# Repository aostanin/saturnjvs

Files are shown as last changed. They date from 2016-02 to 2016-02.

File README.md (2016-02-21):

# SaturnJVS

A project to build a replacement JVS I/O board for a NAOMI arcade board which uses Sega Saturn controllers as input.

## Details

This relies on two boards which communicate by I2C. One board handles JVS communication with the NAOMI while the other handles controller input from Sega Saturn controllers. Originally, the plan was to support different types of controllers by swapping controller input boards.

Both boards rely on Atmel AVR ATmega328P microcontrollers and the firmware is written using the Arduino framework. The boards, however, are custom made and not arduino boards (though Arduino boards might be usable as well).

## Status

Using standard Sega Saturn controllers to play games on a NAOMI 2 board works well. There are some missing features including analog pad support and button remapping.

This project is on hold.

## Directory Layout

- `eagle`: Eagle schematics and board layout data.
- `naomi_io`: Firmware for the JVS communication board.
- `saturn_js`: Firmware for the Sega Saturn controller board.

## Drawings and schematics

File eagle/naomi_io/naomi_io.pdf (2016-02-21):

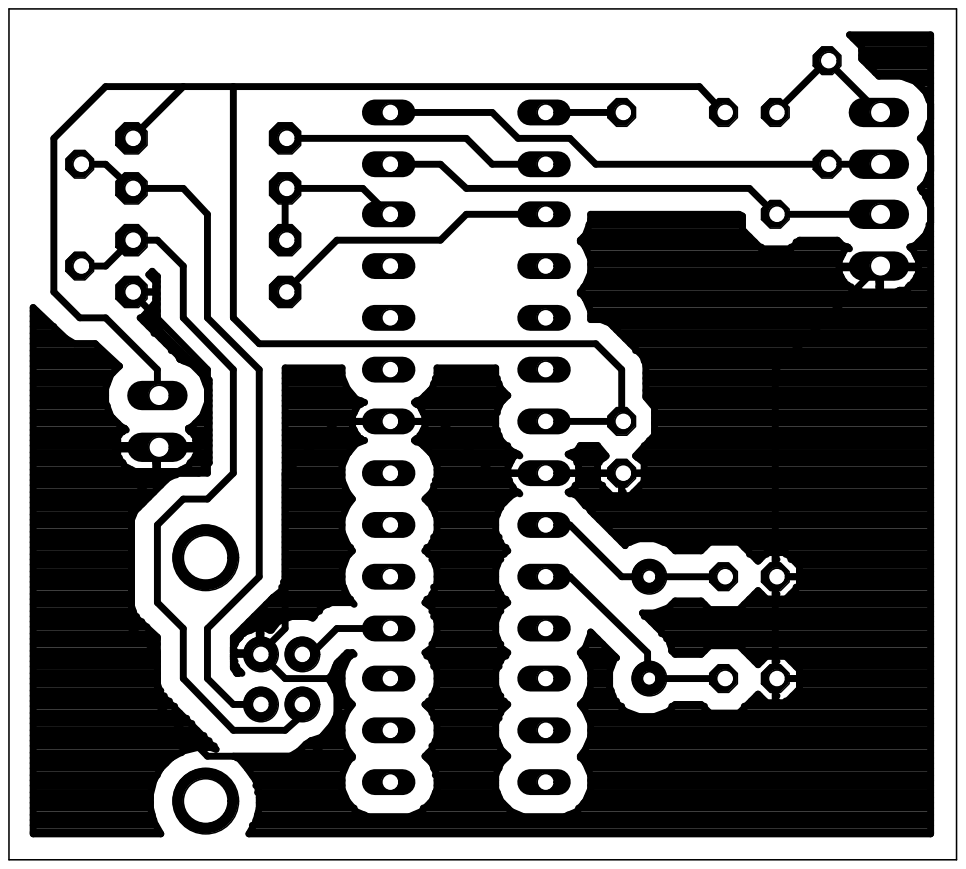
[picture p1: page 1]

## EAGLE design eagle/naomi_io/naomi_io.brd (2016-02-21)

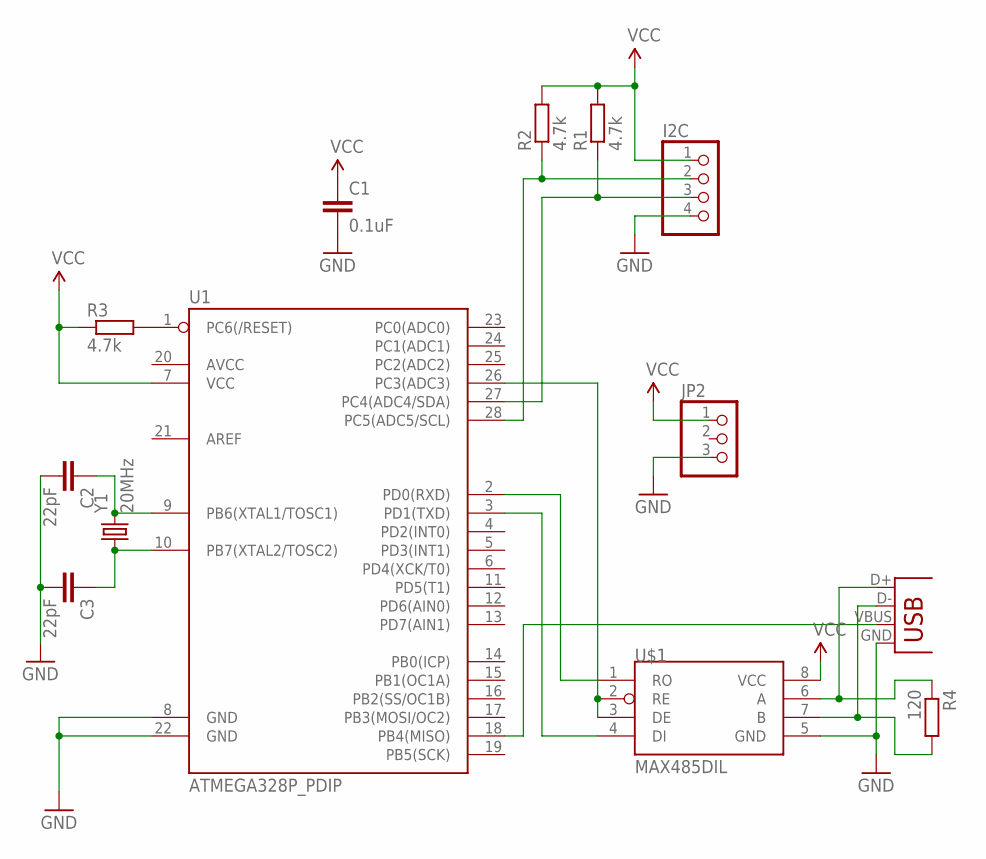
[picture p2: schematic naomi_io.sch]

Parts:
C1: 0.1uF; C025-030X050
C2, C3: 22pF; C025-030X050
I2C: PINHD-1X4/90; 1X04/90
JP1: USB-B; USB-B-PTH
JP2: PINHD-1X3; 1X03
R1, R2, R3: 4.7k; 0204/5
R4: 120; 0204/5
U1: ATMEGA328P_PDIP; DIL28-3
U$1: MAX485DIL; DIL08
Y1: 20MHz; HC49US

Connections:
GND: C1.2, C2.2, C3.2, I2C.4, JP1.GND, JP2.3, U1.8 (GND), U1.22 (GND), U$1.5 (GND)
unnamed: I2C.2, R2.1, U1.28 (PC5(ADC5/SCL))
unnamed: I2C.3, R1.1, U1.27 (PC4(ADC4/SDA))
unnamed: R3.2, U1.1 (PC6(/RESET))
unnamed: JP1.D-, R4.2, U$1.7 (B)
unnamed: U1.2 (PD0(RXD)), U$1.1 (RO)
unnamed: U1.3 (PD1(TXD)), U$1.4 (DI)
unnamed: JP1.VBUS, U1.18 (PB4(MISO))
unnamed: U1.26 (PC3(ADC3)), U$1.2 (RE), U$1.3 (DE)
unnamed: C2.1, U1.9 (PB6(XTAL1/TOSC1)), Y1.2
unnamed: C3.1, U1.10 (PB7(XTAL2/TOSC2)), Y1.1
unnamed: JP1.D+, R4.1, U$1.6 (A)
VCC: C1.1, I2C.1, JP2.1, R1.2, R2.2, R3.1, U1.7 (VCC), U$1.8 (VCC)

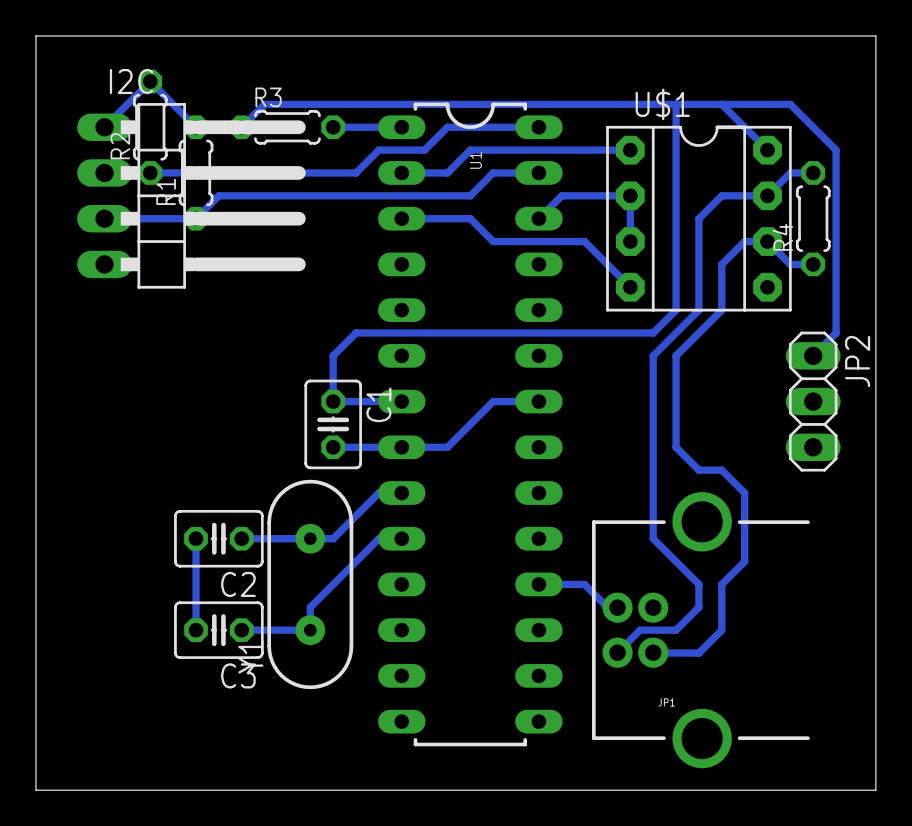
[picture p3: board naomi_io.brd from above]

Board: 2 copper layers, 46.7 x 41.9 mm, 13 parts (0 on the bottom side), 13 nets.

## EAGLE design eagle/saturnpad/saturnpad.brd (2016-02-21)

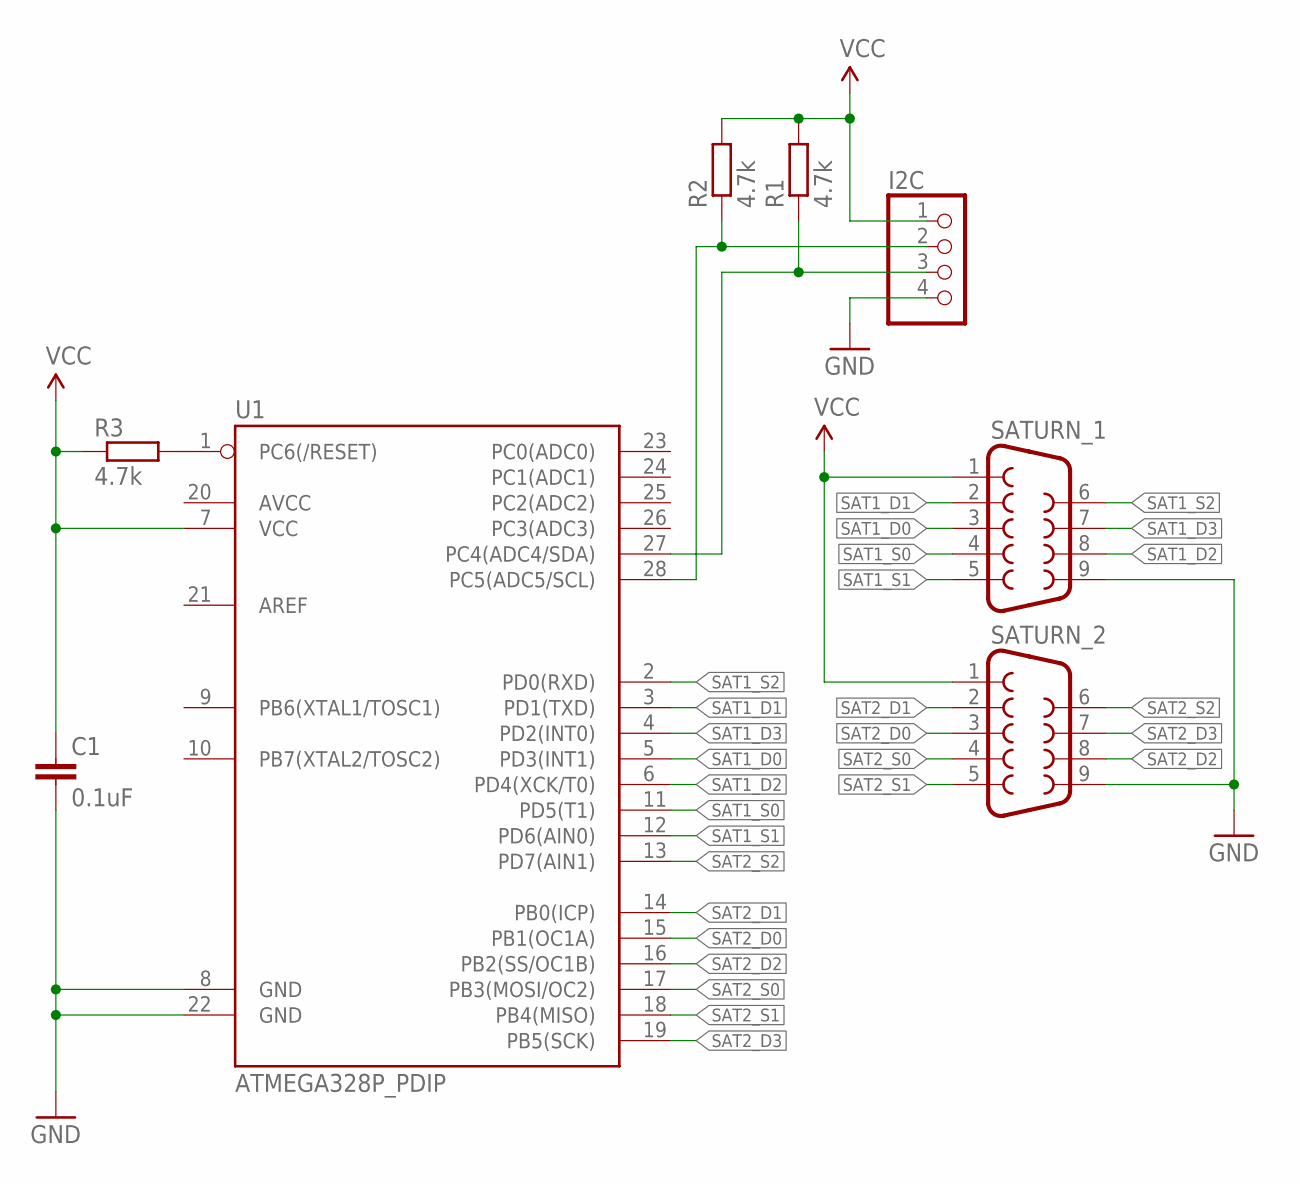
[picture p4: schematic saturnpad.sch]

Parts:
C1: 0.1uF; C025-030X050
I2C: PINHD-1X4/90; 1X04/90
R1, R2, R3: 4.7k; 0204/5
SATURN_1, SATURN_2: DB9MALE; DB9_MALE
U1: ATMEGA328P_PDIP; DIL28-3

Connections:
GND: C1.2, I2C.4, SATURN_1.9, SATURN_2.9, U1.8 (GND), U1.22 (GND)
unnamed: I2C.2, R2.1, U1.28 (PC5(ADC5/SCL))
unnamed: I2C.3, R1.1, U1.27 (PC4(ADC4/SDA))
unnamed: R3.2, U1.1 (PC6(/RESET))
SAT1_D0: SATURN_1.3, U1.5 (PD3(INT1))
SAT1_D1: SATURN_1.2, U1.3 (PD1(TXD))
SAT1_D2: SATURN_1.8, U1.6 (PD4(XCK/T0))
SAT1_D3: SATURN_1.7, U1.4 (PD2(INT0))
SAT1_S0: SATURN_1.4, U1.11 (PD5(T1))
SAT1_S1: SATURN_1.5, U1.12 (PD6(AIN0))
SAT1_S2: SATURN_1.6, U1.2 (PD0(RXD))
SAT2_D0: SATURN_2.3, U1.15 (PB1(OC1A))
SAT2_D1: SATURN_2.2, U1.14 (PB0(ICP))
SAT2_D2: SATURN_2.8, U1.16 (PB2(SS/OC1B))
SAT2_D3: SATURN_2.7, U1.19 (PB5(SCK))
SAT2_S0: SATURN_2.4, U1.17 (PB3(MOSI/OC2))
SAT2_S1: SATURN_2.5, U1.18 (PB4(MISO))
SAT2_S2: SATURN_2.6, U1.13 (PD7(AIN1))
VCC: C1.1, I2C.1, R1.2, R2.2, R3.1, SATURN_1.1, SATURN_2.1, U1.7 (VCC)

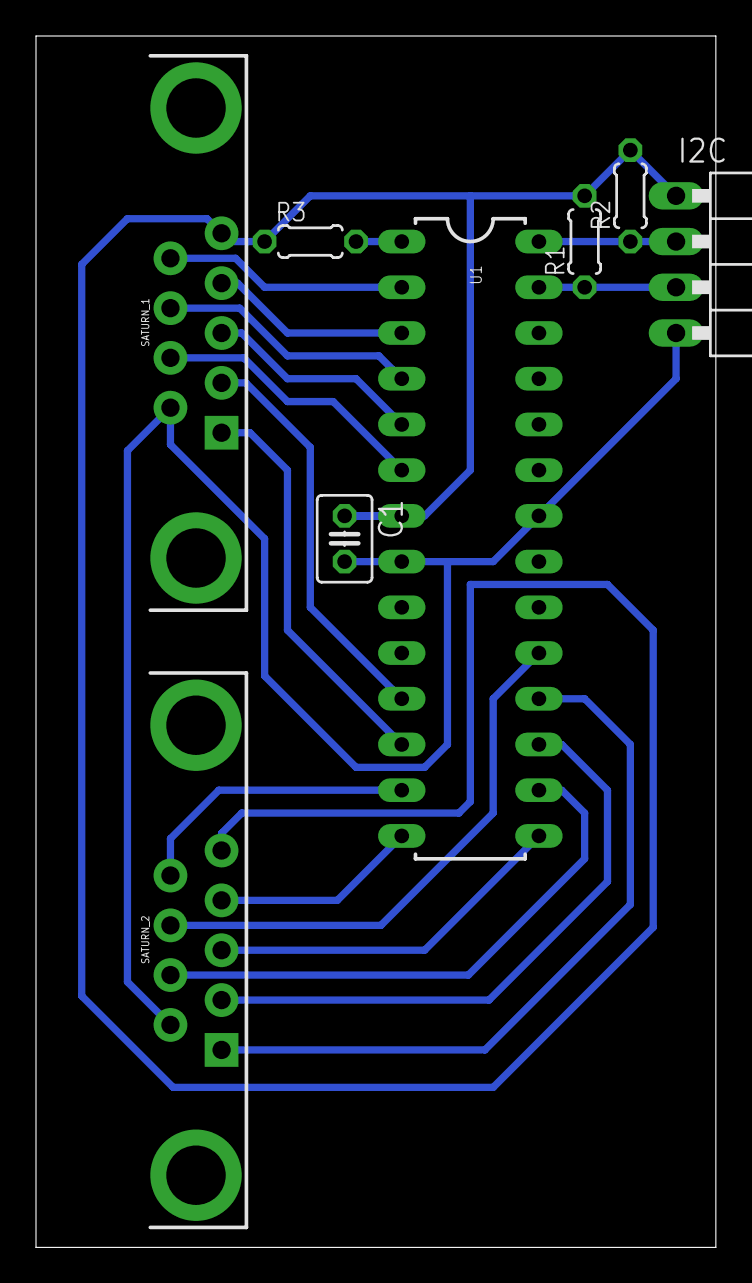
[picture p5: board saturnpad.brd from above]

Board: 2 copper layers, 37.8 x 67.3 mm, 8 parts (0 on the bottom side), 19 nets.

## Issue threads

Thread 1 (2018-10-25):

cannot find the pin or bit for coins.

crazyjojo0251, 2018-10-25:
how can I make a coin?

crazyjojo0251, 2018-10-25:
thanks for your reply,I will have a check for it.
There are somethings I can tell u with the JVS since I made an  PCB with openjvs,so you can notice these point while update your project.
1.the 485 module from different manufactures maybe  not as good as the same,
2.if Naomi donot get the response from IO it will loop again,so when them communicate success， the IO node shows a big number.
3.if add XY analogs for FPS games,the analog bit must be a stranger value and the coin bit enable in games.
4.if add analogs for driving games, many of them cannot get enough keys, such as 18 wheels.

Hope you can make a batter JVS.

crazyjojo0251, 2018-10-25:
The version in your link is the same one I used,most useful information is already listed in OPENJVS wiki,the other are about format of analog and keyboard  ,if you need translations for some command just send me a list,I will photo my notes to you,that maybe help.

And I test the coin part in your program,some games ignore the count of coinbank after reset,so the credit always shows 0 unless get one new coin,lock the coinbank to 8000 donot work for them,the coin bit is necessary.

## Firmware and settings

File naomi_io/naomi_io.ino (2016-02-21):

#include "JVS.h"
#include "Wire.h"

JVS jvs(Serial, A3, 12);

enum Command {
  COMMAND_INFO = 0x10,
  COMMAND_STATUS = 0x20,
};

struct DigitalStatus {
  uint8_t button_start:1;
  uint8_t button_up:1;
  uint8_t button_down:1;
  uint8_t button_left:1;
  uint8_t button_right:1;
  uint8_t button_1:1;
  uint8_t button_2:1;
  uint8_t button_3:1;
  uint8_t button_4:1;
  uint8_t button_5:1;
  uint8_t button_6:1;
  uint8_t button_7:1;
  uint8_t button_8:1;
};

struct ControllerStatus {
  DigitalStatus digital;
  uint8_t *analog;
};

struct ControllerBoard {
  uint8_t controller_count;
  uint8_t digital_count;
  uint8_t analog_count;
  ControllerStatus *controllers;
};

ControllerBoard *controllerBoard = NULL;

void switchStatusCallback(uint8_t controller, JVS::PlayerSwitchStatus *switchStatus)
{
  ControllerStatus *controllerStatus = &controllerBoard->controllers[controller];
  DigitalStatus *digital = &controllerStatus->digital;

  switchStatus->button_start = digital->button_start;
  switchStatus->button_up = digital->button_up;
  switchStatus->button_down = digital->button_down;
  switchStatus->button_left = digital->button_left;
  switchStatus->button_right = digital->button_right;
  switchStatus->button_1 = digital->button_1;
  switchStatus->button_2 = digital->button_2;
  switchStatus->button_3 = digital->button_3;
  switchStatus->button_4 = digital->button_4;
  switchStatus->button_5 = digital->button_5;
  switchStatus->button_6 = digital->button_6;
  switchStatus->button_7 = digital->button_7;
  switchStatus->button_8 = digital->button_8;
}

void setup()
{
  Wire.begin();

  jvs.begin();
  jvs.setSwitchStatusCallback(&switchStatusCallback);
}

void commandInfo()
{
  Wire.beginTransmission(2);
  Wire.write(COMMAND_INFO);
  Wire.endTransmission();

  delayMicroseconds(500);

  Wire.requestFrom(2, 3);
  if (Wire.available() == 3) {
    controllerBoard = (ControllerBoard *)calloc(1, sizeof(ControllerBoard));
    controllerBoard->controller_count = Wire.read();
    controllerBoard->digital_count = Wire.read();
    controllerBoard->analog_count = Wire.read();

    controllerBoard->controllers = (ControllerStatus *)calloc(controllerBoard->controller_count, sizeof(ControllerStatus));
    for (uint8_t controllerIdx = 0; controllerIdx < controllerBoard->controller_count; controllerIdx++) {
      ControllerStatus *controller = &controllerBoard->controllers[controllerIdx];
      controller->analog = (uint8_t *)calloc(controllerBoard->analog_count, sizeof(uint8_t));
    }
  }
}

void commandStatus()
{
  Wire.beginTransmission(2);
  Wire.write(COMMAND_STATUS);
  Wire.endTransmission();

  delayMicroseconds(500);

  uint8_t responseLength = controllerBoard->controller_count * (2 + controllerBoard->analog_count);
  Wire.requestFrom((uint8_t)2, responseLength);
  if (Wire.available() == responseLength) {
    for (uint8_t controllerIdx = 0; controllerIdx < controllerBoard->controller_count; controllerIdx++) {
      ControllerStatus *controller = &controllerBoard->controllers[controllerIdx];
      ((uint8_t *)&(controller->digital))[0] = Wire.read();
      ((uint8_t *)&(controller->digital))[1] = Wire.read();
      for (uint8_t analogIdx = 0; analogIdx < controllerBoard->analog_count; analogIdx++) {
        controller->analog[analogIdx] = Wire.read();
      }
    }
  }
}

void loop()
{
  if (jvs.loop()) {
    if (controllerBoard == NULL) {
      commandInfo();
    } else {
      commandStatus();
    }
  }
}

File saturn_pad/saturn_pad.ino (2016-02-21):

#include "SaturnPad.h"
#include <Wire.h>

SaturnPad pad1(5, 6, 0, 3, 1, 4, 2);
SaturnPad pad2(11, 12, 7, 9, 8, 10, 13);

enum Command {
  COMMAND_INFO = 0x10,
  COMMAND_STATUS = 0x20,
};

struct DigitalStatus {
  uint8_t button_start:1;
  uint8_t button_up:1;
  uint8_t button_down:1;
  uint8_t button_left:1;
  uint8_t button_right:1;
  uint8_t button_1:1;
  uint8_t button_2:1;
  uint8_t button_3:1;
  uint8_t button_4:1;
  uint8_t button_5:1;
  uint8_t button_6:1;
  uint8_t button_7:1;
  uint8_t button_8:1;
};

Command lastCommand;

void respondInfo()
{
  // 2 controllers, 13 digital, 4 analog
  uint8_t response[] = { 2, 13, 4 };
  Wire.write(response, 3);
}

void respondStatus()
{
  uint8_t responseLength = 2 * 2 * 4;
  uint8_t response[responseLength];
  memset(response, 0, responseLength);

  for (uint8_t controllerIdx = 0; controllerIdx < 2; controllerIdx++) {
    SaturnPad::DigitalPadState state;
    switch (controllerIdx) {
      case 0:
        state = pad1.digitalPadState();
        break;
      case 1:
        state = pad2.digitalPadState();
        break;
    }

    DigitalStatus *digitalStatus = (DigitalStatus *)(response + controllerIdx * (2 + 4));

    digitalStatus->button_start = state.button_start;
    digitalStatus->button_up = state.button_up;
    digitalStatus->button_down = state.button_down;
    digitalStatus->button_left = state.button_left;
    digitalStatus->button_right = state.button_right;
    digitalStatus->button_1 = state.button_x;
    digitalStatus->button_2 = state.button_y;
    digitalStatus->button_3 = state.button_z;
    digitalStatus->button_4 = state.button_a;
    digitalStatus->button_5 = state.button_b;
    digitalStatus->button_6 = state.button_c;
    digitalStatus->button_7 = state.button_l;
    digitalStatus->button_8 = state.button_r;

    for (uint8_t analogIdx = 0; analogIdx < 4; analogIdx++) {
      uint8_t *analog = (uint8_t *)digitalStatus + 2 + analogIdx;
      *analog = 0;
    }
  }

  Wire.write(response, responseLength);
}

void dataReceived(int numBytes)
{
  lastCommand = (Command)Wire.read();
}

void dataRequested()
{
  switch (lastCommand) {
    case COMMAND_INFO:
      respondInfo();
      break;

    case COMMAND_STATUS:
      respondStatus();
      break;
  }
}

void setup()
{
  pad1.begin();
  pad2.begin();

  Wire.begin(2);
  Wire.onReceive(dataReceived);
  Wire.onRequest(dataRequested);
}

void loop()
{
  pad1.loop();
  pad2.loop();
}

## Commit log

2014-05-26 Remove debug code and fix runtime problem on AVR
    [JVS.cpp, naomi_io.ino]
2014-05-26 fix pin numbers for final board
    [saturn_pad.ino]
2014-05-27 Add rotary switch support
2014-08-21 Oops... JVS expects the top row of buttons to be 1 2 3 and bottom to be 4 5 6
2016-02-21 add fuses config
2016-02-21 add eagle files
    [naomi_io.brd, naomi_io.sch, saturnpad.brd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]

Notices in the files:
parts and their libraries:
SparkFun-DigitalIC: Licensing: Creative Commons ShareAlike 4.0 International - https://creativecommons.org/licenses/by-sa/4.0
